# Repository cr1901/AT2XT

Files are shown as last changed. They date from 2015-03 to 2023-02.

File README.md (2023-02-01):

# AT-to-XT Keyboard Protocol Converter




(https://github.com/cr1901/AT2XT)



This repository provides the source, schematics, and Gerber files that converts
the AT-keyboard protocol to the XT keyboard protocol. As XT keyboards are
expensive (seriously, type in "PC XT keyboard" or "PC 5150 keyboard" in Ebay),
this provides a cheaper alternative for someone willing to wait for PCB and
parts. This circuit supports 101-key extended keyboards using the XT protocol,
but older pre-386 systems may not know how to handle extended keys. The
extended keycodes are based on a [document](https://download.microsoft.com/download/1/6/1/161ba512-40e2-4cc9-843a-923143f3456c/scancode.doc)
from Microsoft that includes XT keycodes for compatibility.

## Schematics And PCB
Kicad Schematics are provided the [`board`](board) directory. Gerber Files and
an N/C Drill File are provided in the [`gerber`](gerber) directory. A BOM is
provided in [`at2xtv200_BOM.csv`](at2xtv200_BOM.csv).

You can get boards made using my shared [OSHPark Project](https://oshpark.com/shared_projects/AXSJvSh9),
and parts using my shared (_to the extent I could figure out how to share it_)
[Mouser Project](https://www.mouser.com/ProjectManager/ProjectDetail.aspx?AccessID=fe2f22f0a4).

## Building The Firmware (Rust Source)
As an experiment to test the MSP430 Rust/LLVM backend, the current source has
been rewritten in Rust. All future development will be in Rust. The rewrite
is not _exactly_ semantically equivalent to the C source code; in particular,
in the Rust version, the keyhandling Finite State Machine (FSM) returns
immediately and I/O processing occurs in the main loop. In the C version the
FSM _is_ the main loop, and I/O processing is embedded.

### Minimum Supported Rust Version
In theory, the Minimum Supported Rust Version is "the most recently nightly
available from `rustup` that doesn't break CI". When CI breaks, I notice within
a few days (and I've been meaning to set up a GHA to tell me when it breaks).

In practice, I run `rustup update` every 6 weeks during the Thursday release,
and have not run into problems using a 6 week old `nightly` compiler for AT2XT.

### Prerequisites
This source requires the Rust nightly compiler for the foreseeable future due
to the use of `abi_msp430_interrupt` [feature](https://doc.rust-lang.org/unstable-book/language-features/abi-msp430-interrupt.html).

1. Make sure `git` (for AT2XT), `curl` (for `rustup`), `gcc` (for [proc macros](https://doc.rust-lang.org/reference/procedural-macros.html)),
   and optionally `wget` (for downloading `msp430-elf-gcc`) and `just` (for
   convenience) are installed.

2. Visit the rustup [website](https://www.rustup.rs) and follow the
   instructions to first get `rustc` plus `cargo`.

3. Obtain `msp430-elf-gcc` from TI at the bottom of [this page](http://www.ti.com/tool/msp430-gcc-opensource),
   and make sure the toolchain's bin directory is visible to Rust. Until LLVM
   gets linker support for msp430, binutils is required for the linker.

### Build Command
_As of this writing (1-31-2023), AT2XT can be built using the standard
`cargo build --release`._

#### `.cargo/config` and `rust-toolchain.toml`
Thanks to the [`.cargo/config`](.cargo/config) and [`rust-toolchain.toml`](rust-toolchain.toml)
files, the nightly compiler and compiler source will be downloaded, and
`cargo` will automatically target the built-in `msp430-none-elf` target.

Additionally, MSP430 needs a `libcore` installed that doesn't conflict w/ your host,
and an MSP430 `libcore` is not currently provided as part of the toolchain. The
_unstable_ `cargo` feature `-Zbuild-std=core` allows a developer to build
a `libcore` as part of building your application; `.cargo/config` also takes
care of this step. 

For completeness' sake, the full command to build AT2XT (using `rustup` as a
toolchain manager) is:

```
cargo +nightly build --release -Zbuild-std=core --target=msp430-none-elf
```

#### Justfile
Historically, the build command has changed over time, so I provided a
[Justfile](https://github.com/casey/just) to build AT2XT as well. The Justfile
has mostly been superceded by the above files, and at this point consists of
personal recipes I use for development and CI.

For those interested, run `just --list` for a list of avilable recipes. The
build can be further customized by setting the following variables on the
`just` command line (e.g. `just MODE=release`):

* `MODE`: `release` or `debug`. Defaults to `release`, which _must_ be paired
  with the `--release` option to `cargo`.
* `CFLAGS`: Flags to pass to `cargo`. Defaults to `--release -Zbuild-std=core --target=msp430-none-elf`;
  the `-Zbuild-std=core` and `--target=msp430-none-elf` flags are
  unconditionally required, but `--release` should be unset if doing a `debug`
  build.

## Historical Context And Legacy Source
### Building Older Versions Of The Rust Firmware
When this firmware was first rewritten in Rust in 2017, `nightly` features,
nightly (literally!) code additions, and dependencies were subject to breaking
changes much more frequently than today (1-31-2023). While I was still getting
comfortable with Rust, I did not set up CI to figure out which `nightlies` or
dependency changes broke the build. 

In retrospect, this was a mistake; sometimes the build broke for several
months, such as with this [ThinLTO bug](https://github.com/japaric/xargo/issues/158).
Additionally, I tracked branches rather than refs/tags in [git dependencies](https://github.com/cr1901/msp430-rtfm/commit/f6163b7acaeb135e08af1491daded54057e0d59f), so sometimes even having a working
`nightly` would mean the build would break. In 2023, it's difficult for me to
give ranges of working `nightlies` for old versions of AT2XT.

_That said_, it was my intent when porting the code to Rust that tagged commits
should be able to serve as an example of how to write
bare-metal Rust applications using a variety of different code structures and
varying number of external dependencies (see CHANGELOG.md). It should be
possible with moderate effort to port old tags of AT2XT to modern `nightlies`,
though I have no plans to do this. Additionally, with a proper `nightly` compiler installed, previous
versions should still be able to compile/function with a small to moderate
amount of work (see [Data Layout](#data-layout)). Maybe I'll try a [bisect](https://github.com/rust-lang/cargo-bisect-rustc)
in the future for fun and populate a table of working nightlies for tags :D.

#### RTIC/RTFM
Long ago, AT2XT was implemented using the a proof-of-concept version of the [RTIC framework](https://rtic.rs/1/book/en/)
for MSP430 (back when it was known as the RTFM framework). This support
disappeared in `v3.0.0` of the firmware while removing [API unsoundness](https://blog.japaric.io/brave-new-io/)
elsewhere. I looked into porting doing a more proper port of RTIC in late 2019,
but never followed through. At present (1-31-2023), it is not in my plans to
reintroduce RTIC to AT2XT.

#### Data Layout
The MSP430 data layout changed between the time I started writing this
firmware (June 12, 2017) and as of this writing (July 16, 2017). Recent
nightly compilers will crash with custom provided layout up until commit
c85088c. The data layout in `msp430.json` before this commit should be:
`e-m:e-p:16:16-i32:16-i64:16-f32:16-f64:16-a:8-n8:16-S16`.

MSP430 became a supported target within Rust nightly in July 2017, and the
target "triple" changed from `msp430` to `msp430-none-elf`. I switched to the
internal target as of commit c0dc9b9, but the immediate commit prior c85088c
shows how to generate an equivalent binary with the originally-used custom
target.

### Original AT2XT C Source
For comparison purposes, I have kept the old C-based source code as well under
the `legacy-src` directory.

Currently, it is up to the user to set up their toolchain to compile the files
for programming an MSP430G2211 or compatible 14-pin DIP MSP430. I recommend the
former, if only because MSP430 is already overkill for this project and G2211
is a low-end model :P. However, I . When the C source was written, TI expected
users to compile with Code Composer Studio (CCS). Today, I provide a generic
Makefile instead. To compile, invoke `make`; there is only a single target,
`at2xt.elf`. This requires the `msp430-elf-gcc` toolchain from the
[Prerequisites](#prerequisites) section.

The C source code itself should be easy to port to other microcontrollers,
except for the use of a `__delay_cycles()` intrinsic. I had no choice here, as
using the timer for a software delay can lock the keyboard FSM to a single
state.

### XTATKEY.ASM
One of the original XT to AT keyboard converters was written by [Chuck Guzis](http://www.vcfed.org/forum/member.php?3458-Chuck(G))
in 2009. By my own admission, PIC is a better fit for this project due to 5V
compatibility and fewer parts required. However, I wrote my version in 2013
because of my familiarity with msp430, easy [5V interfacing](http://www.ti.com/lit/an/slaa148a/slaa148a.pdf)
and easy access to parts and an msp430 programmer. In contrast, PIC programmers
at the time were expensive ([less true](https://www.microchip.com/developmenttools/ProductDetails/PartNO/PG164100)
today), and I didn't feel like buying or making one.

However, since I've used Chuck(G)'s version as inspiration when I got stuck,
I have provided the [source](http://www.vcfed.org/forum/showthread.php?15907-AT-to-XT-Keyboard-Converter&p=106297#post106297)
and [schematics](http://www.vcfed.org/forum/showthread.php?15907-AT-to-XT-Keyboard-Converter&p=106341#post106341)
to his version- _with permission_- under the `legacy-src/XTATKEY` directory.
See linked forum posts for details.

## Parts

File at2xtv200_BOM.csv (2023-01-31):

Source: | C:\msys64\home\William\Projects\legacy\AT2XT\board\at2xt.kicad_sch
Date: | 1/20/2023 1:07:05 PM
Tool: | Eeschema (6.0.10)
Generator: | C:\Program Files\KiCad\6.0\bin\scripting\plugins/bom_csv_grouped_by_value.py
Component Count: | 15
Individual Components:
Item | Qty | Reference(s) | Value | LibPart | Footprint | Datasheet | MFR | MPN | OC_DIGIKEY | OC_MOUSER | URL_DIGIKEY | URL_MOUSER
 |  | C1 | 2.2u | Device:C | Capacitor_SMD:C_0603_1608Metric | https://datasheets.kyocera-avx.com/X7RDielectric.pdf | Kyocera AVX | 0603YD225KAT2A | 478-5147-2-ND | 581-0603YD225K | https://www.digikey.com/en/products/detail/kyocera-avx/0603YD225KAT2A/1545047 | https://www.mouser.com/ProductDetail/KYOCERA-AVX/0603YD225KAT2A?qs=yeMJfaiNeLw88cYpZCw84Q%3D%3D
 |  | C2 | 2.2u | Device:C | Capacitor_SMD:C_0603_1608Metric | https://datasheets.kyocera-avx.com/X7RDielectric.pdf | Kyocera AVX | 0603YD225KAT2A | 478-5147-2-ND | 581-0603YD225K | https://www.digikey.com/en/products/detail/kyocera-avx/0603YD225KAT2A/1545047 | https://www.mouser.com/ProductDetail/KYOCERA-AVX/0603YD225KAT2A?qs=yeMJfaiNeLw88cYpZCw84Q%3D%3D
 |  | C3 | 1.1n | Device:C | Capacitor_SMD:C_0603_1608Metric | https://datasheets.kyocera-avx.com/X7RDielectric.pdf | Kyocera AVX | 06033C112KAT2A | 06033C112KAT2A-ND | 581-06033C112KAT2A | https://www.digikey.com/en/products/detail/kyocera-avx/06033C112KAT2A/1599375 | https://www.mouser.com/ProductDetail/KYOCERA-AVX/06033C112KAT2A?qs=EbDiPP9peV8hs81P1YU3Ig%3D%3D
 |  | C4 | 100n | Device:C | Capacitor_SMD:C_0603_1608Metric | https://datasheets.kyocera-avx.com/X7RDielectric.pdf | Kyocera AVX | 0603YC104KAT2A | 478-1239-2-ND | 581-06035C104KAT2A | https://www.digikey.com/en/products/detail/kyocera-avx/0603YC104KAT2A/563349 | https://www.mouser.com/ProductDetail/KYOCERA-AVX/0603YC104KAT2A?qs=8tyLnVRzLzw3XjZuBMXbVA%3D%3D
 |  | J1 | Conn_01x04 | Connector_Generic:Conn_01x04 | Connector_PinHeader_2.54mm:PinHeader_1x04_P2.54mm_Vertical | https://www.mouser.com/datasheet/2/527/tsw_th-2854687.pdf | Samtec | TSW-104-14-S-S | SAM1057-04-ND | 200-TSW10414SS | https://www.digikey.com/en/products/detail/samtec-inc/TSW-104-14-S-S/1102720 | https://www.mouser.com/ProductDetail/Samtec/TSW-104-14-S-S?qs=rU5fayqh%252BE1aHgnZ8sRbLw%3D%3D
 |  | J2 | XT | Connector:DIN-5_180degree | at2xt:DIN41524-5-2MP_20.5mmx15.5mm_P7.5mm_P10.0mm_MP10.0mm | https://www.mouser.com/datasheet/2/222/KCDX-334811.pdf | Kycon | KCDX-5S-N | 2092-KCDX-5S-N-ND | 806-KCDX-5S-N | https://www.digikey.com/en/products/detail/kycon-inc/KCDX-5S-N/10246509 | https://www.mouser.com/ProductDetail/Kycon/KCDX-5S-N?qs=uMQTibCNu0QKDGeRAj6hLg%3D%3D
 |  | J3 | AT | Connector:DIN-5_180degree | at2xt:DIN41524-5-2MP_20.5mmx15.5mm_P7.5mm_P10.0mm_MP10.0mm | https://www.mouser.com/datasheet/2/222/KCDX-334811.pdf | Kycon | KCDX-5S-N | 2092-KCDX-5S-N-ND | 806-KCDX-5S-N | https://www.digikey.com/en/products/detail/kycon-inc/KCDX-5S-N/10246509 | https://www.mouser.com/ProductDetail/Kycon/KCDX-5S-N?qs=uMQTibCNu0QKDGeRAj6hLg%3D%3D
 |  | J4 | PS/2 | Connector:Mini-DIN-6 | at2xt:MiniDIN-6-3MP_14.0mmx12.9mm_P2.6mm_P6.8mm_MP6.75mm | https://www.kycon.com/2013Catalogpage/Mini-Dins%20%20Circular%20Dins/KMDGX.pdf | Kycon | KMDGX-6S-N | 2092-KMDGX-6S-BS-ND | 806-KMDGX-6S-BS | https://www.digikey.com/en/products/detail/kycon-inc/KMDGX-6S-BS/9990075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 | https://www.mouser.com/ProductDetail/Kycon/KMDGX-6S-BS?qs=gomZSfZNELc%252BcxHiGAVThw%3D%3D
 |  | R1 | 47k | Device:R_US | Resistor_SMD:R_0603_1608Metric | https://industrial.panasonic.com/ww/products/pt/general-purpose-chip-resistors/models/ERJ3GEYJ473V | Panasonic | ERJ-3GEYJ473V | P47KGTR-ND | 667-ERJ-3GEYJ473V | https://www.digikey.com/en/products/detail/panasonic-electronic-components/ERJ-3GEYJ473V/135787 | https://www.mouser.com/ProductDetail/Panasonic/ERJ-3GEYJ473V
 |  | R2 | 300 | Device:R_US | Resistor_SMD:R_0603_1608Metric | https://industrial.panasonic.com/ww/products/pt/general-purpose-chip-resistors/models/ERJ3GEYJ301V | Panasonic | ERJ-3GEYJ301V | P300GTR-ND | 667-ERJ-3GEYJ301V | https://www.digikey.com/en/products/detail/panasonic-electronic-components/ERJ-3GEYJ301V/29175 | https://www.mouser.com/ProductDetail/Panasonic/ERJ-3GEYJ301V
 |  | R3 | 300 | Device:R_US | Resistor_SMD:R_0603_1608Metric | https://industrial.panasonic.com/ww/products/pt/general-purpose-chip-resistors/models/ERJ3GEYJ301V | Panasonic | ERJ-3GEYJ301V | P300GTR-ND | 667-ERJ-3GEYJ301V | https://www.digikey.com/en/products/detail/panasonic-electronic-components/ERJ-3GEYJ301V/29175 | https://www.mouser.com/ProductDetail/Panasonic/ERJ-3GEYJ301V
 |  | R4 | 300 | Device:R_US | Resistor_SMD:R_0603_1608Metric | https://industrial.panasonic.com/ww/products/pt/general-purpose-chip-resistors/models/ERJ3GEYJ301V | Panasonic | ERJ-3GEYJ301V | P300GTR-ND | 667-ERJ-3GEYJ301V | https://www.digikey.com/en/products/detail/panasonic-electronic-components/ERJ-3GEYJ301V/29175 | https://www.mouser.com/ProductDetail/Panasonic/ERJ-3GEYJ301V
 |  | R5 | 300 | Device:R_US | Resistor_SMD:R_0603_1608Metric | https://industrial.panasonic.com/ww/products/pt/general-purpose-chip-resistors/models/ERJ3GEYJ301V | Panasonic | ERJ-3GEYJ301V | P300GTR-ND | 667-ERJ-3GEYJ301V | https://www.digikey.com/en/products/detail/panasonic-electronic-components/ERJ-3GEYJ301V/29175 | https://www.mouser.com/ProductDetail/Panasonic/ERJ-3GEYJ301V
 |  | U1 | MCP1700x-330xxMB | Regulator_Linear:MCP1700x-330xxMB | Package_TO_SOT_SMD:SOT-89-3 | http://ww1.microchip.com/downloads/en/DeviceDoc/20001826D.pdf | Microchip | MCP1700T-3302E/MB | MCP1700T3302EMBTR-ND | 579-MCP1700T3302E/MB | https://www.digikey.com/en/products/detail/microchip-technology/MCP1700T-3302E-MB/652678 | https://www.mouser.com/ProductDetail/Microchip-Technology-Atmel/MCP1700T-3302E-MB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
 |  | U2 | MSP430G2211IPW14 | MCU_Texas_MSP430:MSP430G2211IPW14 | Package_SO:TSSOP-14_4.4x5mm_P0.65mm | http://www.ti.com/lit/ds/symlink/msp430g2211.pdf | Texas Instruments | MSP430G2211IPW14 | 296-25830-5-ND | 595-MSP430G2211IPW14 | https://www.digikey.com/en/products/detail/texas-instruments/MSP430G2211IPW14/2237185 | https://www.mouser.com/ProductDetail/Texas-Instruments/MSP430G2211IPW14?qs=4bIC7PpGAjJQ2Jf7fQ1jUg%3D%3D
Collated Components:
Item | Qty | Reference(s) | Value | LibPart | Footprint | Datasheet | MFR | MPN | OC_DIGIKEY | OC_MOUSER | URL_DIGIKEY | URL_MOUSER
1 | 2 | C1, C2 | 2.2u | Device:C | Capacitor_SMD:C_0603_1608Metric | https://datasheets.kyocera-avx.com/X7RDielectric.pdf | Kyocera AVX | 0603YD225KAT2A | 478-5147-2-ND | 581-0603YD225K | https://www.digikey.com/en/products/detail/kyocera-avx/0603YD225KAT2A/1545047 | https://www.mouser.com/ProductDetail/KYOCERA-AVX/0603YD225KAT2A?qs=yeMJfaiNeLw88cYpZCw84Q%3D%3D
2 | 1 | C3 | 1.1n | Device:C | Capacitor_SMD:C_0603_1608Metric | https://datasheets.kyocera-avx.com/X7RDielectric.pdf | Kyocera AVX | 06033C112KAT2A | 06033C112KAT2A-ND | 581-06033C112KAT2A | https://www.digikey.com/en/products/detail/kyocera-avx/06033C112KAT2A/1599375 | https://www.mouser.com/ProductDetail/KYOCERA-AVX/06033C112KAT2A?qs=EbDiPP9peV8hs81P1YU3Ig%3D%3D
3 | 1 | C4 | 100n | Device:C | Capacitor_SMD:C_0603_1608Metric | https://datasheets.kyocera-avx.com/X7RDielectric.pdf | Kyocera AVX | 0603YC104KAT2A | 478-1239-2-ND | 581-06035C104KAT2A | https://www.digikey.com/en/products/detail/kyocera-avx/0603YC104KAT2A/563349 | https://www.mouser.com/ProductDetail/KYOCERA-AVX/0603YC104KAT2A?qs=8tyLnVRzLzw3XjZuBMXbVA%3D%3D
4 | 1 | J1 | Conn_01x04 | Connector_Generic:Conn_01x04 | Connector_PinHeader_2.54mm:PinHeader_1x04_P2.54mm_Vertical | https://www.mouser.com/datasheet/2/527/tsw_th-2854687.pdf | Samtec | TSW-104-14-S-S | SAM1057-04-ND | 200-TSW10414SS | https://www.digikey.com/en/products/detail/samtec-inc/TSW-104-14-S-S/1102720 | https://www.mouser.com/ProductDetail/Samtec/TSW-104-14-S-S?qs=rU5fayqh%252BE1aHgnZ8sRbLw%3D%3D
5 | 1 | J2 | XT | Connector:DIN-5_180degree | at2xt:DIN41524-5-2MP_20.5mmx15.5mm_P7.5mm_P10.0mm_MP10.0mm | https://www.mouser.com/datasheet/2/222/KCDX-334811.pdf | Kycon | KCDX-5S-N | 2092-KCDX-5S-N-ND | 806-KCDX-5S-N | https://www.digikey.com/en/products/detail/kycon-inc/KCDX-5S-N/10246509 | https://www.mouser.com/ProductDetail/Kycon/KCDX-5S-N?qs=uMQTibCNu0QKDGeRAj6hLg%3D%3D
6 | 1 | J3 | AT | Connector:DIN-5_180degree | at2xt:DIN41524-5-2MP_20.5mmx15.5mm_P7.5mm_P10.0mm_MP10.0mm | https://www.mouser.com/datasheet/2/222/KCDX-334811.pdf | Kycon | KCDX-5S-N | 2092-KCDX-5S-N-ND | 806-KCDX-5S-N | https://www.digikey.com/en/products/detail/kycon-inc/KCDX-5S-N/10246509 | https://www.mouser.com/ProductDetail/Kycon/KCDX-5S-N?qs=uMQTibCNu0QKDGeRAj6hLg%3D%3D
7 | 1 | J4 | PS/2 | Connector:Mini-DIN-6 | at2xt:MiniDIN-6-3MP_14.0mmx12.9mm_P2.6mm_P6.8mm_MP6.75mm | https://www.kycon.com/2013Catalogpage/Mini-Dins%20%20Circular%20Dins/KMDGX.pdf | Kycon | KMDGX-6S-N | 2092-KMDGX-6S-BS-ND | 806-KMDGX-6S-BS | https://www.digikey.com/en/products/detail/kycon-inc/KMDGX-6S-BS/9990075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 | https://www.mouser.com/ProductDetail/Kycon/KMDGX-6S-BS?qs=gomZSfZNELc%252BcxHiGAVThw%3D%3D
8 | 1 | R1 | 47k | Device:R_US | Resistor_SMD:R_0603_1608Metric | https://industrial.panasonic.com/ww/products/pt/general-purpose-chip-resistors/models/ERJ3GEYJ473V | Panasonic | ERJ-3GEYJ473V | P47KGTR-ND | 667-ERJ-3GEYJ473V | https://www.digikey.com/en/products/detail/panasonic-electronic-components/ERJ-3GEYJ473V/135787 | https://www.mouser.com/ProductDetail/Panasonic/ERJ-3GEYJ473V
9 | 4 | R2, R3, R4, R5 | 300 | Device:R_US | Resistor_SMD:R_0603_1608Metric | https://industrial.panasonic.com/ww/products/pt/general-purpose-chip-resistors/models/ERJ3GEYJ301V | Panasonic | ERJ-3GEYJ301V | P300GTR-ND | 667-ERJ-3GEYJ301V | https://www.digikey.com/en/products/detail/panasonic-electronic-components/ERJ-3GEYJ301V/29175 | https://www.mouser.com/ProductDetail/Panasonic/ERJ-3GEYJ301V
10 | 1 | U1 | MCP1700x-330xxMB | Regulator_Linear:MCP1700x-330xxMB | Package_TO_SOT_SMD:SOT-89-3 | http://ww1.microchip.com/downloads/en/DeviceDoc/20001826D.pdf | Microchip | MCP1700T-3302E/MB | MCP1700T3302EMBTR-ND | 579-MCP1700T3302E/MB | https://www.digikey.com/en/products/detail/microchip-technology/MCP1700T-3302E-MB/652678 | https://www.mouser.com/ProductDetail/Microchip-Technology-Atmel/MCP1700T-3302E-MB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
11 | 1 | U2 | MSP430G2211IPW14 | MCU_Texas_MSP430:MSP430G2211IPW14 | Package_SO:TSSOP-14_4.4x5mm_P0.65mm | http://www.ti.com/lit/ds/symlink/msp430g2211.pdf | Texas Instruments | MSP430G2211IPW14 | 296-25830-5-ND | 595-MSP430G2211IPW14 | https://www.digikey.com/en/products/detail/texas-instruments/MSP430G2211IPW14/2237185 | https://www.mouser.com/ProductDetail/Texas-Instruments/MSP430G2211IPW14?qs=4bIC7PpGAjJQ2Jf7fQ1jUg%3D%3D

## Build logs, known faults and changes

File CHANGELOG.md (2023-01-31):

# Changelog
All notable changes to this project will be documented in this file.

The format is based on [Keep a Changelog](http://keepachangelog.com/en/1.0.0/).
This project does _not_ strictly adhere to semantic versioning. Major version
changes are reserved for code restructuring changes. Minor version changes
are reserved for collections of changes that justify incrementing the version
number. The patch level was only used once and then abandoned,
as optimizations, bugs, and code cleanup are pooled into minor releases.

# AT2XT Firmware
## [Unreleased]

## [4.2.0]
Version [4.2.0] is a checkpoint release before a number of useful branches are
merged (including a new PCB!).

### Added
- Add `rust-toolchain.toml` to automatically choose the nightly compiler and
  download the compiler source (required for `-Zbuild-std` to work) when
  using a `rustc` from [`rustup`](https://rustup.rs/).
- Add `[build]` and `[unstable]` sections to `.cargo/config`, so
  `cargo build --release` alone works.
- Emit assembly file(s) in `Justfile` `timer-extra` target.
- Explicitly allow `Justfile` to utilized `.env` files via `set dotenv-load`.

### Fixed
- Removed a redundant critical section in `IN_BUFFER` management loop to save
  ~30 bytes or so.
- Althought used soundly in AT2XT, `enable_cs` is in general [unsound](https://github.com/rust-embedded/bare-metal/issues/42)
  because as of [`v1.0.0`][bm-v1.0.0], the [bare-metal] `CriticalSection` is
  `Copy`/`Clone`. To solve this, leverage the new `interrupt_enable` argument
  to the [msp430-rt] `entry` attribute to safely enable interrupts.
- Fix Github CI [API limits](https://github.com/extractions/setup-just/issues/9)
  in [`setup-just`](https://github.com/extractions/setup-just) step.
- Derive a 1.6MHz+ clock from 1MHz calibration data. The previous hardcoded
  `RSEL=8`, `DCO=3`, `MOD=0` would result in too low a clock frequency for
  handling interrupts on some MSP430G2211 samples.
  - As a side effect, properly document how clocks are set up in `init`.

### Changed
- Switch from deprecated [msp430-atomic] to [portable-atomic].
- Switch from deprecated [bare-metal](https://github.com/rust-embedded/bare-metal)
  to a custom [fork](https://github.com/cr1901/msp430-cs/tree/msp430-cs) of the
  repacement [critical-section] crate. Using the main repo is pending on
  [rust-lang/rust/issues/102295](https://github.com/rust-lang/rust/issues/102295)
  being fixed.

  Before [bare-metal] was deprecated, AT2XT was updated to use [`v1.0.0`][bm-v1.0.0],
  where `CriticalSection` is `Copy`/`Clone`. In [theory](https://github.com/rust-embedded/bare-metal/pull/20),
  this should allow more optimizations because `CriticalSection` is a
  Zero-Sized Type (ZST), but `&CriticalSection` is the size of a pointer.
- Update [msp430], [msp430-rt], [msp430g2211], and [panic-msp430] crates to
  `v0.3.0` ([bare-metal `v1.0.0`][bm-v1.0.0]), then `v0.4.0` ([critical-section]).
  - AT2XT methods now consume `CriticalSection` tokens instead of passing them
    by reference.
  - `driver` module and `PortWrite` trait cleaned up to reflect newer
    [msp430g2211] APIs.

### Removed
- Remove errant `unwrap` outside of `init`, `main`, and interrupts and replace
  with `?`. This saves a few bytes, and also constrains all of AT2XT's
  `unwrap`s to top-level functions within the root (`main.rs`) module.

## [4.1.0]
Version [4.1.0] further improves the refactor of [4.0.0]. _All `unsafe` code
has been removed as of this version!_ The binary still compiles to about ~2000
bytes and ~50 bytes of RAM. In subsequent releases, I may reintroduce
controlled `unsafe` to get size optimizations impossible under the assumptions
of purely safe code.

### Added
- With permission, [Chuck Guzis](http://www.vcfed.org/forum/member.php?3458-Chuck(G))'s
  original `XTATKEY` firmware implementation is provided in the
  `legacy-src/XTATKEY` direction.
- `#![deny(unsafe_code)]` lint is active.
- The C code in `legacy-src` can now be built and linked with `clang`. I
  have not tested the resulting binary, however; I use `clang` to compare
  binary size with `msp430-elf-gcc` and `rustc`.
- Github CI [support](https://github.com/cr1901/AT2XT/actions).

### Fixed
- Most `clippy` suggestions up to Rust `1.56` were applied. These include:
  - Camel-case for enum variants.
  - Remove redundant closures.
  - Remove complex condition in while loop that tries to borrow `IN_BUFFER`.
  - Remove redundant `CriticalSectionToken` borrows.

  Having a non-empty `Result::Err` variant return from AT2XT functions will
  be addressed later.

### Changed
- `KeyOut::put` uses the `count_ones` intrinsic for parity calculation. This
  saves about 16 bytes. Although `reverse_bits` also exists as a method in
  Rust as of `1.37.0`, the [bit_reverse] crate implementation is still leaner.
- `At2XtPeripherals` was moved to its own `peripheral` module to facilitate
  a safe abstraction boundary (hide the `OnceCell` which permits access
  to peripherals via a `CriticalSectionToken`).
- When possible, replace `match` statements on `Option`s/`Result`s with `ok_or`
  and `map_or` respectively. This change is zero-cost.
- Create a `PortWrite` trait in an attempt to abstract away writes to the I/O
  ports.
- Use `cargo`'s unstable `-Z build-std=core` [option](https://doc.rust-lang.org/cargo/reference/unstable.html#build-std)
  is now used to build `libcore`.
- Generate more build artifacts using `timer` and `timer-extra` `just` targets.
- Until upstream support is added for the new `asm!` macro, use version `0.1.2`
  of the [msp430-atomic] crate with the always-unstable `llvm_asm!` macro.
- The README.md and `Justfile` has been brought up to date in light of the
  other changes.

### Removed
- All `unsafe` code is gone from the AT2XT binary crate! This was due to a few
  factors:
  - I concluded that `enable_at_clk_int` cannot cause memory unsafety because
    interrupts are _already_ disabled by the time you can call this function.
    Spurious pin interrupts are undesireable, but should not cause memory
    safety issues (data races) due to the various `Cells`. See commit 1fd2619.
  - [msp430] version `0.2.2` provides a safe function to enable interrupts
    by consuming a `CriticalSectionToken`, which ensures interrupts are already
    disabled and cannot be re-enabled while the token is borrowed for
    peripheral access. AFAIK, this functionality requires proc macros to
    implement, which weren't really a thing when I first wrote this firmware
    and the [msp430] crate was released.
  - [msp430g2211] version `0.2.1` permits safe access to all bits of the
    `TACCRx` timer count/capturer registers and most of the `Px` I/O port
    registers.
- Because `cargo` is now capable of building AT2XT, `xargo` is no longer used
  to build libcore.
- Travis CI support was removed as part of migrating to Github CI.

## [4.0.0]
Version [4.0.0] is a refactor. The firmware fundamentally operates the same
way as version [3.0.0]. In fact, based on a binary comparison, the firmware
size and contents barely changed.

### Added
- [clippy](https://github.com/rust-lang/rust-clippy) and `xargo fix` lint
  support.
- [rustfmt](https://github.com/rust-lang/rustfmt) support.
- Various `Justfile` targets to support the above.

### Fixed
- Warnings fixed via `just fix` and `just fix-clippy`.
- `KeyIn` was missing a check to prevent shifting in data to a full buffer.
  Because of how `KeyIn` is used, this check is _probably_ not necessary for
  AT2XT, but the check is needed if I were to spin out the `keybuffer` module
  as its own crate. This check pessimizes AT2XT by 10 bytes.
- Some `unwrap`s that are no longer misoptimized were added back in.
- Issue #3 is finally fixed by 7354cc1 thanks to LLVM improvments (the commit
  message points to wrong issue)!

### Changed
- Various refactors, including:
  - `Pins` struct and `led_mask` `u8` replaced with dedicated types using
    the [bitflags](https://github.com/bitflags/bitflags) crate.
  - `set/clear_bits_with_mask` macros replaced with generic functions.
  - Most `u8` literals are referenced using associated constants.
  - All array indexing operations were successfully removed.
  - Most as-conversions replaced with `From` impl.
  - Anything else suggested by clippy. Some of these optimizations saved space,
    such as rearranging match arms.

### Removed
- Software-based delay loop support was removed, as there aren't enough
  space optimizations left in AT2XT compared to justify the configuration
  boilerplate. `just timer` is now the default build configuration.
- `feature(asm)` is no longer necessary due to the above.
- After Issue #3 was resolved, the `driver` module refactor from 7aaffcc
  removed the affected code.

## [3.0.0]
Version [3.0.0] is the first version of AT2XT using the newer `take`-based
[singleton API](https://blog.japaric.io/brave-new-io/).

### Added
- `Makefile` for C code in `legacy-src` directory for comparison purposes
  (only 2.5 years late!).

### Fixed
- `KeycodeBuffer` now checks if the queue is full, and will not overwrite old
  entries if the queue is full.

### Changed
- Use `CriticalSection`s/`msp430::interrupt::free` as appropriate to access
  I/O.
- Use [msp430-rt] version `0.2.4` to get access to `CriticalSection`
  optimizations- saving approximately 60 bytes.
- Various optimizations to further save space (~60 more bytes), including:
  - `KeycodeBuffer`'s bounds checks are optimized out.
  - `keymap::to_xt()` returns `Option<u8>`; processing the `None` variant
     saves space.
  - Combined `CriticalSection`s when exiting `while` loops.
- Most functions now return `Result<(),()>`, which offsets the size gains
  pretty much exactly.

### Removed
- Remove the ancient RTFM version for now, pending a rewrite of [msp430-rtfm]
  to target a newer API [version](https://rtfm.rs/0.5/book/en/) of
  [Real Time For the Masses](http://www.rtfm-lang.org).

### Deprecated
- The software-based delay loop was removed in the following commit.
  `just timer` is now the default target.

## [2.3.0]
Version [2.3.0] is a stopgap release meant to provide a clean break between
the old unsound `borrow`-based peripherals API and the newer `take`-based
[singleton API](https://blog.japaric.io/brave-new-io/). Switching AT2XT to the
`take`-based API (_without RTFM for now_) warrants a major version bump.

### Changed
- The [panic-msp430] crate now provides the `panic_handler` language item.
  We have removed our own implementation of the same.
- `cargo` profile configuration options were simplified so that
  [default](https://doc.rust-lang.org/cargo/reference/manifest.html) values
  are now implicit. This aids in simplifying the `Cargo.toml` of future
  projects.

### Removed
- `Makefile` was removed in favor of using the Rust-based [just](https://github.com/casey/just)
  command runner.
- `.cargo/config` rustflags that appear to have no effect on binary contents
  _or can be provided by the `cargo` manifest_ were removed. This aids in
  simplifying the `.cargo/config` of future projects.
- `const_fn` feature was stabilized, so corresponding feature attribute is no
  longer needed. _The only remaining unstable features are `asm` (for software
  delay loops only) and `abi_msp430_interrupt`._

## [2.2.0]
The following is a "cleanup" release. Nightly Rust did not work properly on
msp430 from approx
[July 7, 2018](https://travis-ci.org/cr1901/AT2XT/builds/401135317) to
[Oct 31, 2018](https://travis-ci.org/cr1901/AT2XT/builds/448735034).

In this  time frame, `rustc` learned to shave 40 or so bytes off the final
binary in `-Os`! Contrast to
[July 6, 2018](https://travis-ci.org/cr1901/AT2XT/builds/400722102) build.

Additional changes, which are found in the
[commit history](https://github.com/cr1901/AT2XT/compare/v2.1.0...v2.2.0),
include keeping AT2XT up to date with the enabled/disabled features of the
nightly compiler _at the time_. Some of these changes, such as the
`proc_macro_gen` feature gate, appeared _and_ disappeared between [2.1.0]
and [2.2.0].

### Added
- Travis CI [support](https://travis-ci.org/cr1901/AT2XT).
- Various README.md improvements.
- Do not depend on [msp430-rt]'s `panic_implementation`; it is set for
removal (and `panic_implementation` does not exist in recent nightlies).
Instead, since `panic_handler` is stable, we provide our own implementation.
- Support version `6.4.0` of `msp430-elf-gcc`.

### Fixed
- Fix multiple warnings, particularly of the following types:
  - Unnecessary mutability
  - Unnecessary parentheses

### Changed
- Use [msp430-atomic] crate available on
[crates.io](https://crates.io/crates/msp430-atomic).
- Output `msp430-elf-readelf` symbols in wide format for better debugging.
- [msp430-rtfm] syntax/semantics changed in a manner that significantly
increased code size. Although the
bug has since been
[fixed](https://github.com/japaric/cortex-m-rtfm/issues/41), there has not
been much progress in checking that the fix works on msp430. Instead for now,
we pin AT2XT to a [known working]
(https://github.com/cr1901/msp430-rtfm/tree/at2xt-pin) version of
[msp430-rtfm].
- Remove unsafety in `keymap` module, now that `rustc` will correctly remove
bounds check and/or not bring in panic strings (I haven't checked).
- LLVM misoptimizes calls to `Pin::bitmask()` in some cases; they aren't
treated as a function returning a compile-time constant. Provide a
workaround using `const`.

### Removed
- All uses of `Option::unwrap()`; as of before Jan 28, 2018, they add strings
to the binary which AT2XT can't display.

## [2.1.0]
### Added
- Firmware can now be built using `TIMERA` for delay loops instead of a
software delay.
- Changelog added based on tag messages (for commits after/including [1.0.0]).

### Fixed
- Timer functionality was pulled in from a private branch between this release
and the previous, but was non-functional; now fixed. Fixes include:
  - Increase LED toggle wait so firmware doesn't send byte while keyboard is
  still sending response code.
  - Fix busy-wait loop condition for timer.
  - Ensure timer interrupt is enabled.
  - Fix busy-wait tick count for non-timer firmware.

### Changed
- The [msp430g2211] crate was published,
so we use the [crates.io](https://crates.io/crates/msp430g2211) version now.
- Change [bit_reverse] algorithm to `BitwiseReverse` to save approx 18-20 bytes.
- Use the newly-created [msp430-atomic] repository for wait-free `AtomicBool`.
Removes a number of critical sections, thus saving approx 30 bytes.
- Between [2.0.0] and [2.1.0], an [r0](https://github.com/japaric/r0)
[optimization](https://github.com/japaric/r0/blob/master/CHANGELOG.md#v022---2017-07-21)
was added to the published crate, which is then pulled in by [msp430-rt],
[msp430], and [msp430g2211]. This optimization saves between 20 to 40 bytes
(I've seen up to 44 on commit 8c311c6).

### Removed
- Clean up unused dependencies in Cargo.toml file.
- Removed redundant register writes to clear interrupt flag (done by
hardware).

## [2.0.0]
### Added
- Additional README.md changes, installation instruction improvements.
- Code has been restructured to use the [RTFM framework][msp430-rtfm].

### Changed
- RTFM subsumes all responsibilities of [msp430-rt], and provides a macro which
allows hardware to be accessed in interrupts without a `CriticalSection` token.
- Keyboard driver no longer requires critical sections, but now requires an
`rtfm` resource. This resource can either be acquired safely (`rtfm::atomic`,
or within an ISR) or opting into unsafety.

## [1.3.0]
### Added
- Finally updated the long-out-of-date usage/installation instructions.
- Use the [msp430g2211] crate to provide a microcontroller API.

### Changed
- Instead of using symbols representing register addresses provided by the
linker, use [msp430g2211]'s API functions instead. API also prevents leakage
of `unsafe` I/O writes.
- Use [msp430g2211]'s API to provide the interrupt table, which wraps around
[msp430-rt]'s method of populating the table.

### Removed
- Linker script providing I/O addresses no longer necessary, and thus removed.

## [1.2.0]
### Added
- Use the [msp430-rt] crate to provide startup code and interrupt handler API.

### Changed
- Rust nightly provides `msp430-none-elf` target by this point, so use that.
The last commit before the target swap generated an equivalent binary (at
the time) for reproducibility.
- Interrupt handlers are provided using [msp430-rt] API instead of using
`link_section` attribute.
- `memcpy` and `memset` are now provided by [compiler-builtins], a `libgcc`/
`libcompiler_rt` helper crate.

### Removed
- [msp430-rt] provides startup code, including memory initialization via [r0].
No need to call [r0] directly.
  - `panic_fmt` code removed for same reason.
- TI linker script proper no longer necessary, as [msp430-rt] provides
a linker script with everything except the memory map (`memory.x`)
- `libc` no longer linked against directly, thus removed as link library.
[compiler-builtins] still will emit `memcpy`/`memset`, however.

## [1.1.0]
Most space savings were checked a few weeks after [1.0.0]'s release with a more
recent nightly compiler. Some things have changed since then:
- In general, `-O3` no longer compiles.
- Commit b8d4779 now saves space.
I am currently uncertain what changed. This is a footnote to remind me to check
at some point using nightly 07-15-2017 and (approx) 06-12-2017.

### Added
- Use the [r0] crate to provide `.bss` and `.data` initialization. At the time,
this increased binary size by a fair amount.
  - A number of extra linker-script-provided symbols (`__bssstart`,
    `__bssend`) now required.

### Fixed
- `DEVICE_ACK` busy-wait wasn't properly translated to `Cell` encapsulation,
fixed by release.
- [r0] was brought in because the addition of `Mutex` and `Cell` required
global data, and custom init code was insufficient to initialize either of
these. 30 bytes (`-O3`) added for `.data` init, 28 bytes (`-O3`) for .bss init.

### Changed
- The `FSM` in `keyfsm` no longer returns a `Result<State, State>`, but rather
a `State`. _This was a significant savings of 70 bytes_.
- Wrap the globals `HOST_MODE`, `DEVICE_ACK`, `KEY_OUT`, `KEY_IN` in `Cell`s
and use interior mutability to safely mutate globals. Guarantted to be safe
thanks to `free` sections, and size cost is minimal, nearly zero-cost.
  - Due to this, the keyboard driver functions no longer require
  `CriticalSection`s. It's assumed user will grab a token before using these
  functions, unsure safety in some other way, or opt into unsafety
  (increases function usability).
- `IN_BUFFER`, on the other hand, requires a `RefCell` b/c `Array`doesn't
implement `Clone`. Due to  runtime checks (which _I_ know apriori can't fail,
but the compiler doesn't), cost of safety is nonzero.
- Some savings (36 bytes- mutex booleans commit) came from combining
`free` sections. _I don't remember this savings originally._
- The combination of using [r0] startup code, making `IN_BUFFER` safe, means
the code no longer fits into msp430g2211 in `-O3`, so enable `-Os` without
issue.
- `delay` is now considered safe after talking it over in `#rust-embedded`.

### Removed
- Manual initialization of global `.data`/`.bss` is no longer used; use
[r0] instead, at the cost of space. _This enables fair comparisons to
C code, which will normally bring in startup code even for small micros._
- The `util.rs` source file was removed per
[recommendation](https://twitter.com/withoutboats/status/877761222073925633).
- `keymap` module was incorporated as private module into the FSM source file.

## [1.0.1]
### Fixed
- Up to this point, little effort was made to fix warnings. Code was modified
to remove warnings, mainly of the following types (and their fixes):
  - Unused vars (Remove, or `let _ = my_unused_var;`)
  - Unused imports (Remove)
  - Unused features (Remove)
  - Dead code (`#[allow(dead_code)]`)
  - Snake case for structs (e.g. `state` => `State`)
  - Redundant and unnecessary `unsafe` blocks (Remove)
  - Additional changes:
    - `allow(private_no_mangle_fns)]` for `panic_fmt` dance
    - Function name fixes (no capital letters)

### Changed
- Now that the firmware is known to work, I start importing already-existing
crates to automate work I did manually.
  - [bare-metal] crate provides a generic `CriticalSection`, so replace
    `CriticalSectionToken` => `CriticalSection`.
  - [msp430] crate provides interrupt helpers, as well as `critical_section`,
    so replace `critical_section` => `free`.
  - Neither of the above changes add to code size- truly zero-cost.

### Removed
- Thanks to above changes/crates, `interrupt.rs` no longer provides any
functionality, and thus removed.
- Commented out code cleaned up (mostly no-longer relevant code).

## [1.0.0]
### Added
- Pause/Break handling logic implemented, which must be handled specially.
- First fully functional firmware. This initial release depends on very few
external packages and provides an example of how to write a Rust firmware
taking care of everything manually (aside from a few small helper crates).

## [0.9.5]
### Added
- LED toggling logic added, which requires a special state in the FSM to
send a "light LED command" to the keyboard upon receipt of a break code, before
sending the equivalent break code to the XT host (XT keyboard lights were
not standardized like this).

## [0.9.0]
### Added
- Handle `E0` keycodes in the FSM, which are special keycodes whose first byte
are passed to the XT unchanged. These include _right_ CTRL, SHIFT, ALT, and
arrow keys, for example. Pause must be handled specially, and is not
implemented yet.

## [0.8.0]
### Added
- Actually clear `KeycodeBuffer` when FSM requests it.

### Fixed
- All possible `panic` locations up to this point had been optimized out by
LLVM due to optimizations involving infinite loops. Fix by introducing an `asm`
barrier.
- `panic` implementation exposed at least two more bugs. It was a happy
  accident that `panic` omission generated "working" code:
  - `.bss` initialization needed to be done for initially-zero variables due
  to lack of runtime support.
  - FSM was missing proper state transition back to `state::NotInKey` after
  break code was sent to XT.

## [0.7.0]
### Added
- Implement most of the FSM keycode conversions. Specifically, any key
consisting of a single make code and 2-byte break code on the AT side is now
translated properly to the XT host.
  - This gets quite a bit of functionality, and is likely usable on its own (if
  unpleasant).

### Fixed
- The FSM logic generated multiplication. Since this MSP430 variant does _not_
  have a hardware multiplier, we must use the gcc-provided software
  multiplication routines.

### Changed
- My patch to [bit_reverse] made it to a published version, so use upstream.

## [0.5.0]
This release should have been split into smaller releases. All bugs _and fixes_
introduced _between_ 0.1.0 and [0.5.0] are documented here.

### Added
- Keyboard driver file added (`driver.rs`), which is a truly zero-cost
abstraction for reading and writing the relevant microcontroller pins.
  - Up until after version [1.0.1], `critical_section` was hand-rolled
  and not provided by a crate. _This was mainly an experiment to demonstrate
  how to write Rust firmware without (many) external dependencies._
- `critical_section` implementation added to safely access I/O and mark
`unsafe` I/O writes as truly safe (no data races possible if interrupts
disabled).
- Keyboard buffer abstraction (`keybuffer.rs`) file added for convenience
and abstraction. The file relies on Rust's inlining for buffer operations
to be truly zero-cost.
- Use [volatile_register](https://crates.io/crates/volatile-register) because at the time I didn't understand
[interior mutability](https://doc.rust-lang.org/core/cell/), and Rust's
volatile semantics.
  - Interior mutability allows writing I/O pins without a mutable reference.
  Volatile operations prevent reordering or optimizing I/O R/W away. Volatile
  operations are not at the type level as they are in C.
- Introduce the [bit_reverse] crate to take advantage of code reuse when
  shifting in keyboard data.
- Sending and receiving to keyboard routines, as well as sending to XT host
  are functional.

### Fixed
- Keyboard buffer implementation had a number of bugs
- [bit_reverse] repository did not have support for `usize=16` Rust targets
when I started
- msp430 interrupt enable/disable did not handle pipeline bugs (requires
`nop`s to work properly)

### Removed
- Keyboard driver originally embedded `critical_section`s. This was removed in
favor of passing in `CriticalSectionToken`s.

# AT2XT PCB
The AT2XT PCB follows a different versioning scheme. _Unless otherwise noted,
any version of the AT2XT firmware will function on any version of the board_.
New versions of the PCB do not constitute a version increase in the repository.
Links to versions are the commit where the new version was introduced (as
opposed to a comparison).

# [PCB-1.01]- Circa 2013-09
### Changed
- Second revision of PCBs, using less-hassle through-hole components.
These have the voltage regulator pins swapped on the board, and
should not be manufactured. A new design will follow shortly.

# 0.90- Circa 2013-07
### Added
- Original batch of PCBs using surface mount components. Design is lost to time.

[bit_reverse]: https://github.com/EugeneGonzalez/bit_reverse
[r0]: https://github.com/japaric/r0
[msp430]: https://github.com/rust-embedded/msp430
[msp430-rt]: https://github.com/rust-embedded/msp430-rt
[msp430g2211]: https://github.com/cr1901/msp430g2211
[msp430-rtfm]: https://github.com/japaric/msp430-rtfm
[msp430-atomic]: https://github.com/pftbest/msp430-atomic
[panic-msp430]: https://github.com/YuhanLiin/panic-msp430
[compiler-builtins]: https://github.com/rust-lang-nursery/compiler-builtins
[portable-atomic]: https://github.com/taiki-e/portable-atomic
[critical-section]: https://github.com/rust-embedded/critical-section
[bare-metal]: https://github.com/rust-embedded/bare-metal
[bm-v1.0.0]: https://github.com/rust-embedded/bare-metal/tree/v1.0.0

[Unreleased]: https://github.com/cr1901/AT2XT/compare/v4.2.0...HEAD
[4.2.0]: https://github.com/cr1901/AT2XT/compare/v4.1.0...v4.2.0
[4.1.0]: https://github.com/cr1901/AT2XT/compare/v4.0.0...v4.1.0
[4.0.0]: https://github.com/cr1901/AT2XT/compare/v3.0.0...v4.0.0
[3.0.0]: https://github.com/cr1901/AT2XT/compare/v2.3.0...v3.0.0
[2.3.0]: https://github.com/cr1901/AT2XT/compare/v2.2.0...v2.3.0
[2.2.0]: https://github.com/cr1901/AT2XT/compare/v2.1.0...v2.2.0
[2.1.0]: https://github.com/cr1901/AT2XT/compare/v2.0.0...v2.1.0
[2.0.0]: https://github.com/cr1901/AT2XT/compare/v1.3.0...v2.0.0
[1.3.0]: https://github.com/cr1901/AT2XT/compare/v1.2.0...v1.3.0
[1.2.0]: https://github.com/cr1901/AT2XT/compare/v1.1.0...v1.2.0
[1.1.0]: https://github.com/cr1901/AT2XT/compare/v1.0.1...v1.1.0
[1.0.1]: https://github.com/cr1901/AT2XT/compare/v1.0.0...v1.0.1
[1.0.0]: https://github.com/cr1901/AT2XT/compare/v0.9.5...v1.0.0
[0.9.5]: https://github.com/cr1901/AT2XT/compare/v0.9.0...v0.9.5
[0.9.0]: https://github.com/cr1901/AT2XT/compare/v0.8.0...v0.9.0
[0.8.0]: https://github.com/cr1901/AT2XT/compare/v0.7.0...v0.8.0
[0.7.0]: https://github.com/cr1901/AT2XT/compare/v0.5.0...v0.7.0
[0.5.0]: https://github.com/cr1901/AT2XT/compare/v0.1.0...v0.5.0

[PCB-1.01]: https://github.com/cr1901/AT2XT/commit/7fb0578e1a45b8f2f998aadfc368d10b6378ccda

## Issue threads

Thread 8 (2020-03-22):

PAUSE/BREAK Handling

cr1901, 2020-03-22:
Current AT2XT PAUSE/BREAK behavior (one or more keystrokes) on IBM 5150 is to eat the next keystroke without displaying anything. Subsequent keystrokes display as normal. Changes in lock key states _are_ honored it such a key follows PAUSE/BREAK. However, there seem to be a few edge cases:

* CTRL+BREAK triggers scroll lock LED.
* CTRL+SCROLL also triggers scroll lock LED- supposedly the 5150 Model F keyboard version of CTRL+BREAK _or_ BREAK alone?
* CTRL+NUM emulates pressing the PAUSE/BREAK key, but also triggers num lock LED.

 Check what PAUSE, CTRL+BREAK, and BREAK alone are supposed to do. Also make sure the `self.expecting_pause` optimization didn't introduce this.

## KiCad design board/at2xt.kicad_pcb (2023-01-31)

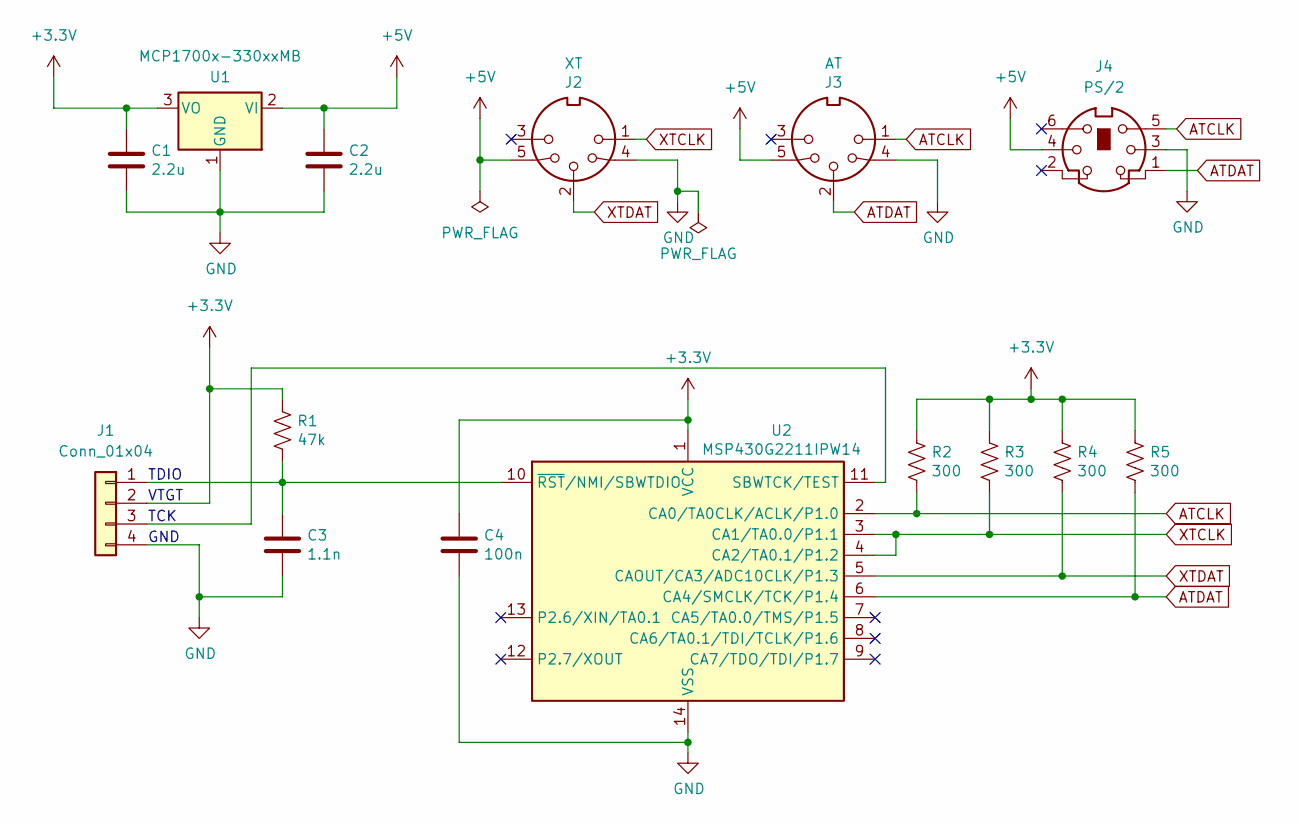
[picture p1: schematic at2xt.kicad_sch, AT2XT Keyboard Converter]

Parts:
C1, C2: 2.2u; C_0603_1608Metric; MPN 0603YD225KAT2A
C3: 1.1n; C_0603_1608Metric; MPN 06033C112KAT2A
C4: 100n; C_0603_1608Metric; MPN 0603YC104KAT2A
J1: Conn_01x04; PinHeader_1x04_P2.54mm_Vertical; MPN TSW-104-14-S-S
J2: XT; DIN41524-5-2MP_20.5mmx15.5mm_P7.5mm_P10.0mm_MP10.0mm; MPN KCDX-5S-N
J3: AT; DIN41524-5-2MP_20.5mmx15.5mm_P7.5mm_P10.0mm_MP10.0mm; MPN KCDX-5S-N
J4: PS/2; MiniDIN-6-3MP_14.0mmx12.9mm_P2.6mm_P6.8mm_MP6.75mm; MPN KMDGX-6S-N
R1: 47k; R_0603_1608Metric; MPN ERJ-3GEYJ473V
R2, R3, R4, R5: 300; R_0603_1608Metric; MPN ERJ-3GEYJ301V
U1: MCP1700x-330xxMB; SOT-89-3; MPN MCP1700T-3302E/MB
U2: MSP430G2211IPW14; TSSOP-14_4.4x5mm_P0.65mm; MPN MSP430G2211IPW14

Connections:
+3.3V: C1.1, C4.1, J1.2, R1.1, R2.1, R3.1, R4.1, R5.1, U1.3 (VO), U2.1 (VCC)
+5V: C2.1, J2.5, J3.5, J4.4, U1.2 (VI)
ATCLK: J3.1, J4.5, R2.2, U2.2 (CA0/TA0CLK/ACLK/P1.0)
ATDAT: J3.2, J4.1, R5.2, U2.6 (CA4/SMCLK/TCK/P1.4)
GND: C1.2, C2.2, C3.2, C4.2, J1.4, J2.4, J3.4, J4.3, U1.1 (GND), U2.14 (VSS)
unnamed: C3.1, J1.1, R1.2, U2.10 (~RST/NMI/SBWTDIO)
unnamed: J1.3, U2.11 (SBWTCK/TEST)
XTCLK: J2.1, R3.2, U2.3 (CA1/TA0.0/P1.1), U2.4 (CA2/TA0.1/P1.2)
XTDAT: J2.2, R4.2, U2.5 (CAOUT/CA3/ADC10CLK/P1.3)

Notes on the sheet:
TDIO
GND
TCK
VTGT

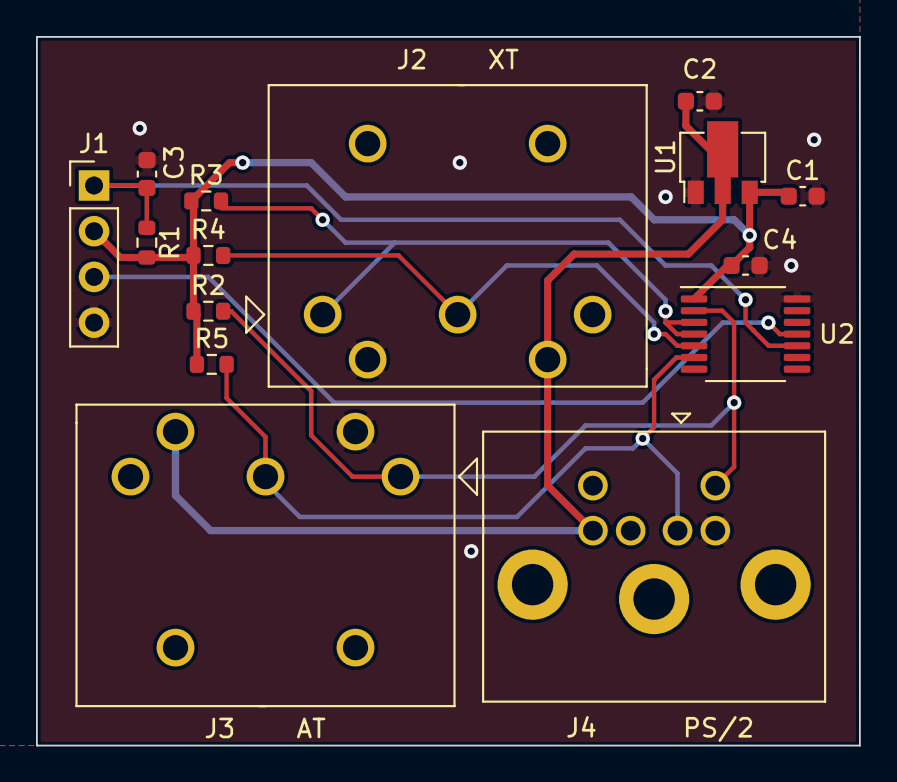
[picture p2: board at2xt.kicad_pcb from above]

Board: 2 copper layers, 45.7 x 39.4 mm, 15 parts (0 on the bottom side), 9 nets.

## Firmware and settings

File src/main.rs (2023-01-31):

#![no_main]
#![no_std]
#![feature(abi_msp430_interrupt)]
#![deny(unsafe_code)]

extern crate panic_msp430;

use bit_reverse::BitwiseReverse;
use core::cell::{Cell, RefCell};
use msp430::{critical_section as mspcs, interrupt::CriticalSection, interrupt::Mutex};
use msp430_rt::entry;
use msp430g2211::{interrupt, Peripherals};
use portable_atomic::{AtomicBool, Ordering};

mod keyfsm;
use keyfsm::{Cmd, Fsm, LedMask, ProcReply};

mod keybuffer;
use keybuffer::{KeyIn, KeyOut, KeycodeBuffer};

mod driver;
use driver::Pins;

mod peripheral;
use peripheral::At2XtPeripherals;

macro_rules! delay_us {
    ($u:expr) => {
        // Timer is 100000 Hz, thus granularity of 10us.
        delay(($u / 10) + 1)
    };
}

static TIMEOUT: AtomicBool = AtomicBool::new(false);
static HOST_MODE: AtomicBool = AtomicBool::new(false);
static DEVICE_ACK: AtomicBool = AtomicBool::new(false);

static IN_BUFFER: Mutex<RefCell<KeycodeBuffer>> = Mutex::new(RefCell::new(KeycodeBuffer::new()));
static KEY_IN: Mutex<Cell<KeyIn>> = Mutex::new(Cell::new(KeyIn::new()));
static KEY_OUT: Mutex<Cell<KeyOut>> = Mutex::new(Cell::new(KeyOut::new()));

#[interrupt]
fn TIMERA0(cs: CriticalSection) {
    TIMEOUT.store(true, Ordering::SeqCst);

    // Use unwrap b/c within interrupt handlers, if we can't get access to
    // peripherals right away, there's no point in continuing.
    let timer: &msp430g2211::TIMER_A2 = At2XtPeripherals::periph_ref(cs).unwrap();
    // Writing 0x0000 stops Timer in MC1.
    timer.taccr0.write(|w| w.taccr0().bits(0x0000));
    // CCIFG will be reset when entering interrupt; no need to clear it.
    // Nesting is disabled, and chances of receiving second CCIFG in the ISR
    // are nonexistant.
}

#[interrupt]
fn PORT1(cs: CriticalSection) {
    let port = At2XtPeripherals::periph_ref(cs).unwrap();

    if HOST_MODE.load(Ordering::SeqCst) {
        let mut keyout = KEY_OUT.borrow(cs).get();

        if let Some(k) = keyout.shift_out() {
            if k {
                driver::set(port, Pins::AT_DATA);
            } else {
                driver::unset(port, Pins::AT_DATA);
            }

            // Immediately after sending out the Stop Bit, we should release the lines.
            if keyout.is_empty() {
                driver::at_idle(port);
            }
        } else {
            // TODO: Is it possible to get a spurious clock interrupt and
            // thus skip this logic?
            if driver::is_unset(port, Pins::AT_DATA) {
                DEVICE_ACK.store(true, Ordering::SeqCst);
                keyout.clear();
            }
        }

        KEY_OUT.borrow(cs).set(keyout);
    } else {
        let mut keyin = KEY_IN.borrow(cs).get();

        // Are the buffer functions safe in nested interrupts? Is it possible to use tokens/manual
        // sync for nested interrupts while not giving up safety?
        // Example: Counter for nest level when updating buffers. If it's ever more than one, panic.
        if keyin.shift_in(driver::is_set(port, Pins::AT_DATA)).is_err() {
            driver::at_inhibit(port); // Ask keyboard to not send anything while processing keycode.

            if let Some(k) = keyin.take() {
                if let Ok(mut b) = IN_BUFFER.borrow(cs).try_borrow_mut() {
                    // Dropping keys when the buffer is full is in line
                    // with what AT/XT hosts do. Saves 2 bytes on panic :)!
                    #[allow(clippy::let_underscore_must_use)]
                    {
                        let _ = b.put(k);
                    }
                }
            }

            keyin.clear();

            driver::at_idle(port);
        }

        KEY_IN.borrow(cs).set(keyin);
    }

    driver::clear_at_clk_int(port);
}

fn init(cs: CriticalSection) {
    let p = Peripherals::take().unwrap();

    p.WATCHDOG_TIMER
        .wdtctl
        .write(|w| w.wdtpw().password().wdthold().set_bit());

    driver::idle(&p.PORT_1_2);

    let calcb1 = p.CALIBRATION_DATA.calbc1_1mhz.read().calbc1_1mhz().bits();
    let caldco = p.CALIBRATION_DATA.calbc1_1mhz.read().calbc1_1mhz().bits();

    // We want a nominally 1.6MHz clock (to get an easily-divisible timer of
    // 100kHz). Higher frequencies are fine, but even a bit lower than 1.6MHz
    // runs into timing problems servicing interrupts IME.
    //
    // According to the MSP430G2211 datasheet:
    // * Every increment of the bottom 4 bits of BCSCTL1 (RSEL) increments the
    //   clock frequency by 1.35.
    // * Every increment of the top 3 bits of DCOCTL (DSO) increments the clock
    //   frequency by 1.08.
    // * The bottom 5 bits of DCOCTL (MOD) fine-tunes the clock frequency
    //   between frequency F and frequency F * 1.08 (except for DSO == 7, in
    //   which case MOD has no effect).
    //
    // For this application, we leave MOD alone, assume RSEL is < 14 (safe for
    // properly calibrated chips), and boost the freq from the calibrated 1MHz
    // value by 1.35^2*1.08. This is closer to 1.70MHz; we add some breathing
    // room because the 1MHz calibration value can vary up to 3% according to
    // the MSP430G2211 datasheet.
    p.SYSTEM_CLOCK
        .bcsctl1
        .write(|w| w.bcsctl1().bits(calcb1 + 2)); // XT2 off, Multiply freq by 1.35^2.
        // Assumes bottom 4 bits < 14, will spill into DIVA bits if violated.
    p.SYSTEM_CLOCK.dcoctl.write(|w| {
        w.dcoctl().bits(if caldco >= 32 {
            caldco - 32 // Divide by 1.08 if DCO bits nonzero.
        } else {
            caldco // Otherwise leave alone.
        })
    });
    p.SYSTEM_CLOCK.bcsctl2.write(|w| w.divs().divs_2()); // Divide submain clock by 4, nominally 400kHz.

    p.TIMER_A2.taccr0.write(|w| w.taccr0().bits(0x0000));
    p.TIMER_A2
        .tactl
        .write(|w| w.tassel().tassel_2().id().id_2().mc().mc_1()); // Divide by 4, use submain clock (100kHz).
    p.TIMER_A2.tacctl0.write(|w| w.ccie().set_bit());

    let shared = At2XtPeripherals {
        port: p.PORT_1_2,
        timer: p.TIMER_A2,
    };

    At2XtPeripherals::init(shared, cs).unwrap();
}

#[entry(interrupt_enable(pre_interrupt = init))]
fn main() -> ! {
    send_byte_to_at_keyboard(Cmd::RESET).unwrap();

    let mut loop_cmd: Cmd;
    let mut loop_reply: ProcReply = ProcReply::init();
    let mut fsm_driver: Fsm = Fsm::start();

    loop {
        // Run state machine/send reply. Receive new cmd.
        loop_cmd = fsm_driver.run(&loop_reply).unwrap();

        loop_reply = match loop_cmd {
            Cmd::ClearBuffer => {
                mspcs::with(|cs| {
                    // XXX: IN_BUFFER.borrow(cs).borrow_mut() and
                    // IN_BUFFER.borrow(cs).try_borrow_mut().unwrap()
                    // bring in dead formatting code! Use explicit
                    // if-let for now and handle errors by doing nothing.

                    if let Ok(mut b) = IN_BUFFER.borrow(cs).try_borrow_mut() {
                        b.flush()
                    }
                });
                ProcReply::ClearedBuffer
            }
            Cmd::ToggleLed(m) => {
                toggle_leds(m).unwrap();
                ProcReply::LedToggled(m)
            }
            Cmd::SendXtKey(k) => {
                send_byte_to_pc(k).unwrap();
                ProcReply::SentKey(k)
            }
            Cmd::WaitForKey => {
                // The micro spends the majority of its life idle. It is possible for the host PC and
                // the keyboard to send data to the micro at the same time. To keep control flow simple,
                // the micro will only respond to host PC acknowledge requests if its idle.
                fn reset_requested() -> bool {
                    mspcs::with(|cs| {
                        let port = At2XtPeripherals::periph_ref(cs).unwrap();

                        driver::is_unset(port, Pins::XT_SENSE)
                    })
                }

                fn attempt_take() -> Option<u16> {
                    mspcs::with(|cs| {
                        IN_BUFFER
                            .borrow(cs)
                            .try_borrow_mut()
                            // Staying in idle state and busy-waiting is reasonable behavior for
                            // now if we couldn't borrow the IN_BUFFER.
                            .map_or(None, |mut b| b.take())
                    })
                }

                loop {
                    if let Some(b_in) = attempt_take() {
                        let mut bits_in = b_in;
                        bits_in &= !(0x4000 + 0x0001); // Mask out start/stop bit.
                        bits_in >>= 2; // Remove stop bit and parity bit (FIXME: Check parity).
                        break ProcReply::GrabbedKey((bits_in as u8).swap_bits());
                    }
                    // If host computer wants to reset
                    if reset_requested() {
                        send_byte_to_at_keyboard(Cmd::RESET).unwrap();
                        send_byte_to_pc(Cmd::SELF_TEST_PASSED).unwrap();
                        break ProcReply::KeyboardReset;
                    }
                }
            }
        }
    }
}

pub fn send_xt_bit(bit: u8) -> Result<(), ()> {
    mspcs::with(|cs| {
        let port = At2XtPeripherals::periph_ref(cs).ok_or(())?;

        if bit == 1 {
            driver::set(port, Pins::XT_DATA);
        } else {
            driver::unset(port, Pins::XT_DATA);
        }

        driver::unset(port, Pins::XT_CLK);

        Ok(())
    })?;

    delay_us!(55)?;

    mspcs::with(|cs| {
        let port = At2XtPeripherals::periph_ref(cs).ok_or(())?;

        driver::set(port, Pins::XT_CLK);
        Ok(())
    })?;

    Ok(())
}

pub fn send_byte_to_pc(mut byte: u8) -> Result<(), ()> {
    fn wait_for_host() -> Result<bool, ()> {
        mspcs::with(|cs| {
            let port = At2XtPeripherals::periph_ref(cs).ok_or(())?;

            let clk_or_data_unset =
                driver::is_unset(port, Pins::XT_CLK) || driver::is_unset(port, Pins::XT_DATA);

            if !clk_or_data_unset {
                driver::xt_out(port);
            }

            Ok(clk_or_data_unset)
        })
    }

    // The host cannot send data; the only communication it can do with the micro is pull
    // the CLK (reset) and DATA (shift register full) low.
    // Wait for the host to release the lines.
    while wait_for_host()? {}

    send_xt_bit(0)?;
    send_xt_bit(1)?;

    for _ in 0..8 {
        send_xt_bit(byte & 0x01)?; /* Send data... */
        byte >>= 1;
    }

    mspcs::with(|cs| {
        let port = At2XtPeripherals::periph_ref(cs).ok_or(())?;

        driver::xt_in(port);
        Ok(())
    })?;

    Ok(())
}

fn send_byte_to_at_keyboard(byte: u8) -> Result<(), ()> {
    // TODO: What does the AT keyboard protocol say about retrying xfers
    // when inhibiting communication? Does the keyboard retry from the beginning
    // or from the interrupted bit? Right now, we don't flush KeyIn, so
    // we do it from the interrupted bit. This seems to work fine.
    fn wait_for_at_keyboard() -> Result<bool, ()> {
        mspcs::with(|cs| {
            let port = At2XtPeripherals::periph_ref(cs).ok_or(())?;

            let unset = driver::is_unset(port, Pins::AT_CLK);

            if !unset {
                driver::at_inhibit(port);
            }

            Ok(unset)
        })
    }

    mspcs::with(|cs| {
        let port = At2XtPeripherals::periph_ref(cs).ok_or(())?;

        let mut key_out = KEY_OUT.borrow(cs).get();

        key_out.put(byte)?;

        // Safe outside of critical section: As long as HOST_MODE is
        // not set, it's not possible for the interrupt
        // context to touch this variable.
        KEY_OUT.borrow(cs).set(key_out);
        driver::disable_at_clk_int(port);
        Ok(())
    })?;

    /* If/when timer int is enabled, this loop really needs to allow preemption during
    I/O read. Can it be done without overhead of CriticalSection? */
    while wait_for_at_keyboard()? {}

    delay_us!(100)?;

    mspcs::with(|cs| {
        let port = At2XtPeripherals::periph_ref(cs).ok_or(())?;

        driver::unset(port, Pins::AT_DATA);
        Ok(())
    })?;

    delay_us!(33)?;

    mspcs::with(|cs| {
        let port = At2XtPeripherals::periph_ref(cs).ok_or(())?;

        driver::set(port, Pins::AT_CLK);
        driver::mk_in(port, Pins::AT_CLK);
        driver::clear_at_clk_int(port);

        driver::enable_at_clk_int(port);
        HOST_MODE.store(true, Ordering::SeqCst);
        DEVICE_ACK.store(false, Ordering::SeqCst);
        Ok(())
    })?;

    while !DEVICE_ACK.load(Ordering::SeqCst) {}

    HOST_MODE.store(false, Ordering::SeqCst);

    Ok(())
}

fn toggle_leds(mask: LedMask) -> Result<(), ()> {
    send_byte_to_at_keyboard(Cmd::SET_LEDS)?;
    delay_us!(3000)?;
    send_byte_to_at_keyboard(mask.bits())?;
    Ok(())
}

fn delay(time: u16) -> Result<(), ()> {
    start_timer(time)?;
    while !TIMEOUT.load(Ordering::SeqCst) {}

    Ok(())
}

fn start_timer(time: u16) -> Result<(), ()> {
    mspcs::with(|cs| {
        let timer: &msp430g2211::TIMER_A2 = At2XtPeripherals::periph_ref(cs).ok_or(())?;

        TIMEOUT.store(false, Ordering::SeqCst);
        timer.taccr0.write(|w| w.taccr0().bits(time));
        Ok(())
    })
}

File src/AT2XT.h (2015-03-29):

#ifndef AT2XT_H_
#define AT2XT_H_

//Useful Macros
#define TRUE 1
#define FALSE 0
#define PAUSE(_x) __delay_cycles(_x*2.1)

#define BIT(_x) (char) 1 << _x
/* This does not do what I expect (casts to int for some reason) */


//PORT1 is closest to voltage regulator on prototype board
#define CAPTURE_P2CLK_PIN 1
#define CAPTURE_P2CLK BIT1

#define PORT1_DATA_PIN 4
#define PORT1_DATA BIT4

#define PORT1_CLK BIT0

#define PORT2_DATA_PIN 3
#define PORT2_DATA BIT3

#define PORT2_CLK BIT2

#define DIRECTION_REG P1DIR
#define INPUT_REG P1IN
#define OUTPUT_REG P1OUT

#define TIMER_FRQ 100000

extern volatile char keycode_buffer[16];
extern volatile char buffer_head, buffer_tail;
extern volatile char timeout;

/* Might be necessary to handle bad keycodes in FSM. */
//extern volatile char BadKeys;


/* buffer_flush is... err, was a debugging function */
void BufferFlush();
void StartTimer(unsigned short clk_cycles);
void StopTimer();
void Stall(unsigned short clk_cycles);
void SendBytetoATKeyboard(char at_code);
void SendBytetoPC(char xt_code);
void InhibitComm();
void IdleComm();
//void SendRTS(PORTS p);
char ComputeParity(unsigned char shifted_byte);
unsigned char ReverseBits(unsigned char b);
void AT2XT_FSM();


#endif /*AT2XT_H_*/

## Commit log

2015-03-29 Initial commit.
    [AT2XTv110_BOM.csv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]
2015-03-29 Remove redundant bottom silk gerber file, fix bad top silk
    [BottomSilk.gbr, TopSilk.gbr]
2017-06-14 Add keyboard pin GPIO driver to move out I/O accesses from main
2017-06-17 Move some regs out of main, add interrupt helper module
2017-06-18 Use critical sections to make GPIO driver safe
2017-06-18 Start interrupt fn. Add inhibit/idle for at side
2017-06-18 Implement interrupt- attempt 1 (does not compile)
2017-06-24 Fix global vars being optimized away.
    [main.rs]
2017-07-02 Fix race condition in checking empty buffer (KeyIn/KeyOut should be okay, as msp430 CMP should be atomic)
    [main.rs]
2017-07-09 Interrupts were never enabled in committed code.
2017-07-11 Fix empty logic check/init value for KeyOut position.
    [main.rs]
2017-07-11 Minor formatting tweaks. All I/O drivers functional.
2017-07-11 Add FSM logic (does not compile due to missing multiplication).
    [main.rs]
2017-07-12 panicking was optimized out by LLVM- fix
    [main.rs]
2017-07-12 Fix initialization error due to lack of .bss zeroing- exposed by working panic impl
    [main.rs]
2017-07-12 Add LED toggle logic.
2017-07-12 Replace hand-rolled interrupt helpers w/ existing crates.
    [main.rs]
2017-07-15 Add .data initialization support (mutexes need it). Still buggy.
    [main.rs]
2017-07-15 Comparison against DEVICE_ACK was incorrect.
2017-07-15 Make accesses to KEY_OUT safe. Remove critical section; make Mutex's responsibility to avoid data race (or opt into unsafety).
    [main.rs]
2017-07-16 IN_BUFFER is safe, but code doesn't fit on -O3.
    [main.rs]
2017-07-16 delay() is probably safe. nop() provided by external crate. Enable -Os to successfully compile. Main loop and interrupt are safe (minus init and toggling an I/O reg. Bump version.
2017-07-16 Replace msp430-rt and manual interrupt handling with msp430g2211.
    [main.rs]
2017-07-16 Use msp430g2211 API in keyboard pin driver. Linker symbols no longer required.
2017-07-16 Add more information on prerequisites and schematic.
2017-07-17 Swap keyboard driver to take PORT_1_2 peripheral directly. Ensure it compiles by commenting out relevant main code.
    [main.rs]
2017-07-19 Replace delay loops with timer (for potential sleep modes)
    [main.rs]
2017-07-23 Use msp430_atomic::AtomicBool to avoid critical sections
    [main.rs]
2017-07-23 Tick count was wrong for not(use-timer) delays. Add Makefile target for timer.
    [main.rs]
2017-07-24 Fix logic error while polling for timeout. Breaks timer firmware, happy accident that it ever worked.
    [main.rs]
2017-07-24 Timer never fired in the first place- enable interrupt.
2017-07-24 Increase LED toggle delay so firmware doesn't start sending next byte while recieving ack from keyboard.
    [main.rs]
2017-07-24 No need to set/reset CCIFG bits; hardware takes care of reset, and timer is only running in busy loops.
    [main.rs]
2017-07-24 Bump version for timer feature. msp430g2211 now on crates.io
2017-07-30 Pin RTFM to before-stable version due to code generation problems.
2018-01-29 CHANGELOG.md format fix, remove Option::unwraps() and unwrap manually, as unwrap() now introduces impossible-to-display strings that didn't exist w/ approx-July 16 nightly.
    [main.rs]
2018-05-29 Add newly-required proc_macro_gen feature gate.
    Required due to #50820 in Rust. RTFM needs the feature to function currently: https://bot.tockos.org/tockbot-moz/embedded-bot/2018-05-29/?msg=97309&page=1
2018-10-31 Feature gate proc_macro_gen and feature proc_macro no longer needed. (#6)
    proc_macro was stabilized in Rust 1.29. See [1] for relevant commit.
    [1] https://github.com/rust-lang/rust/commit/65f3007fa8a08daf77f2b8382a56eb80cb277131
    [main.rs]
2018-11-18 Cleanup driver.rs, provide our own panic_handler- msp430-rt's is outdated.
2020-01-13 Update CHANGELOG.md, fix warnings. Tag v2.3.0.
    [main.rs]
2020-01-15 Add missing cfg feature gates.
    [main.rs]
2020-01-15 Fix typo when porting that caused AT keyboard communication to fail.
    [main.rs]
2020-03-07 Fix msp430-rt minimum version and run cargo fmt.
    [main.rs]
2020-03-07 Remove timer feature- using the timer is now default; there are few space optimizations left to get closer to software-delay size.
2020-03-15 Get rid of KEYBOARD_PINS static- it doesn't do much.
    [main.rs]
2020-03-15 xargo fix w/ clippy.
    [main.rs]
2020-03-15 Manually fix remaining clippy lints.
    [main.rs]
2020-03-16 Add one final lint for now/fix.
    [main.rs]
2020-03-16 Replace custom Pins struct with bitflags crate.
    [main.rs]
2020-03-16 Replace driver macros with generics. No changes in binary.
2020-03-20 Convert LED mask to dedicated bitflag type.
2020-04-04 Create periph_ref_map to replace public periph_ref.
    [main.rs]
2020-04-04 Fix double-reference oversight on periph_ref_map, embed map conversion.
    [main.rs]
2020-04-04 Add original XTATKEY source to tree under legacy-src.
    [XTATKEY.SCH]
2020-04-23 Conclude that enable_at_clk_int is safe- already used in safe code, and all shared accesses require interrupts disabled globally.
2020-04-24 Use msp430 0.2.2 to safely enable interrupts via enable_cs.
2020-05-04 Use cargo's unstable build-std feature instead of Xargo. Bring README.md up to date.
    [main.rs]
2020-08-31 Generate even more artifacts for timer-extra.
2020-09-01 Link in interrupt vectors properly in legacy C code.
2020-09-20 Emit llvm IR as well in timer-extra.
2021-02-24 Add cron build to GHA to track nightly compiler.
2021-02-24 Fix some simple clippy warnings.
    [main.rs]
2021-10-19 Apply most cargo clippy fixes.
    [main.rs]
2022-01-28 Clean up pin driver implementation.
2022-02-20 Remove unsafety by leveraging new interrupt_enable argument to entry.
2022-08-16 Switch from msp430-atomic to portable-atomic.
2022-08-18 Set dotenv-load in Justfile, emit assembly from rustc.
2022-11-08 Convert interrupt::free() to critical_section::with(). Does not link due to size increase.
2022-11-08 Offset size increase by fixing errant unwrap.
    [main.rs]
2022-11-30 Rework IN_BUFFER management in idle loop.
    [main.rs]
2023-01-16 Add Kicad schematic and fully-routed board (finally!). Subject to change.
    [at2xt.kicad_pcb, at2xt.kicad_sch]
2023-01-16 Apply some suggestions from dragonmux's hoard.
    [at2xt.kicad_pcb, at2xt.kicad_sch]
2023-01-16 Apply some more suggestions from dragonmux's hoard.
    [at2xt.kicad_pcb]
2023-01-16 Add .gitattributes for board folder, add name/version to silkscreen.
    [at2xt.kicad_pcb]
2023-01-16 Generate a new set of Gerber files.
    [BoardOutline.gbr, Bottom.gbr, BottomMask.gbr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]
2023-01-16 Remove old DipTrace ASCII schematic, not needed anymore.
2023-01-17 Add OSHPark design rules.
    [at2xt.kicad_pcb]
2023-01-18 Annotate parts, regenerate PCB, gerbers, and drill file.
    [at2xt-B_Cu.gbl, at2xt-B_Mask.gbs, at2xt-B_Paste.gbp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]
2023-01-18 Minor silkscreen fixups, swap out regulator for part readily available from Mouser.
    [at2xt-B_Cu.gbl, at2xt-B_Mask.gbs, at2xt-B_Paste.gbp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]
2023-01-18 Replace old BOM with one for v2.00.
    [AT2XTv110_BOM.csv, at2xtv200_BOM.csv]
2023-01-18 Fix errant value for regulator (wrong identifier, correct package).
    [at2xt-B_Cu.gbl, at2xt-B_Mask.gbs, at2xt-B_Paste.gbp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]
2023-01-18 Regenerate gerbers and drill file (diff claims them to be out of date w/ unmodified PCB file).
    [at2xt-B_Cu.gbl, at2xt-B_Mask.gbs, at2xt-B_Paste.gbp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]
2023-01-18 Update BOM with correct regulator package.
    [at2xtv200_BOM.csv]
2023-01-18 Fixed OC_MOUSER for one of the capacitors.
    [at2xt.kicad_pcb, at2xt.kicad_sch, at2xtv200_BOM.csv]
2023-01-20 More BOM fixes. NFC.
    [at2xt-B_Cu.gbl, at2xt-B_Mask.gbs, at2xt-B_Paste.gbp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]
2023-01-30 Use calibration data to derive 1.6MHz+ clock. Comment init function better. cargo fmt.
